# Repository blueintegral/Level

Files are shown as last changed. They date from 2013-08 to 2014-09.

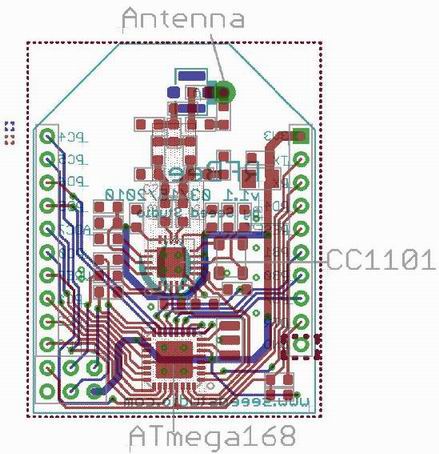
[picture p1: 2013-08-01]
hardware/reference/RFBee-board.jpg

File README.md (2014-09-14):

## Level
#### A node for cognitive radio networks
---
Level is a small, low power and low bandwidth radio for creating and researching cognitive radio networks. It is still in a prototype phase. See the platform paper for a more detailed overview.

###Building
There are two methods to build the firmware. You can use TI's [Code Composer Studio](http://www.ti.com/tool/ccstudio), which is an Eclipse based IDE. Just create a new project and import the files in the firmware/levelfirmware directory. You'll also need to set the target chip to be the cc430f3157.

 You can also use [msp430-gcc](https://github.com/sergiocampama/Launchpad/blob/master/README.md), which has a more libre license than Code Composer Studio. Some of the source files must be modified slightly since interrupt service routine syntax is slightly different. To build, cd into the firmware/levelfirmware/msp430-gcc directory and run "make". To reset the build, run "make clean". 

To save time, I've also been using SimpliciTI as a mesh networking stack. This isn't as free-as-in-speech as I'd like, and I plan on moving away from it. Until then, the license for that code is below.

###License 
The MIT License (MIT)

Copyright (c) [2014] [Hunter Scott]

Permission is hereby granted, free of charge, to any person obtaining a copy
of this software and associated documentation files (the "Software"), to deal
in the Software without restriction, including without limitation the rights
to use, copy, modify, merge, publish, distribute, sublicense, and/or sell
copies of the Software, and to permit persons to whom the Software is
furnished to do so, subject to the following conditions:

The above copyright notice and this permission notice shall be included in all
copies or substantial portions of the Software.

THE SOFTWARE IS PROVIDED "AS IS", WITHOUT WARRANTY OF ANY KIND, EXPRESS OR
IMPLIED, INCLUDING BUT NOT LIMITED TO THE WARRANTIES OF MERCHANTABILITY,
FITNESS FOR A PARTICULAR PURPOSE AND NONINFRINGEMENT. IN NO EVENT SHALL THE
AUTHORS OR COPYRIGHT HOLDERS BE LIABLE FOR ANY CLAIM, DAMAGES OR OTHER
LIABILITY, WHETHER IN AN ACTION OF CONTRACT, TORT OR OTHERWISE, ARISING FROM,
OUT OF OR IN CONNECTION WITH THE SOFTWARE OR THE USE OR OTHER DEALINGS IN THE
SOFTWARE.

All SimpliciTI code is distributed under TI's license agreement, which can be found in "SimpliciTI License Agreement.pdf".

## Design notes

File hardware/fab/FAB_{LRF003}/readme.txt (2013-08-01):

Company Name:         Level RF
PC Board Name:        Level Shield
PC Board Number:      -
Revision:             4
Design House:         Clear River Technical Services Corporation
Designed by:          Tom Atkinson
Contact Number:       (603) 505 - 2376
e-mail:               toma@crtscorp.com

Files Included:

Filename		Description						Format
--------		-----------						------
L1.PHO			Primary Side Cu					Gerber 8.5
L2.PHO			Layer 2   Cu					Gerber 8.5
L3.PHO			Layer 3   Cu					Gerber 8.5
L4.PHO			Secondary Side Cu				Gerber 8.5
PSS.PHO			Primary Silkscreen A/W				Gerber 8.5
SSS.PHO			Secondary Silkscreen A/W			Gerber 8.5
PSM.PHO			Primary Soldermask A/W				Gerber 8.5
SSM.PHO			Secondary Soldermask A/W 			Gerber 8.5
PST.PHO			Primary Solder Stencil A/W 			Gerber 8.5
SST.PHO			Secondary Solder Stencil A/W			Gerber 8.5	  
DD.PHO			Drill Drawing  					Gerber 8.5
DD.PDF			PDF of Drill Drawing				Adobe PDF file
NC_DRILL.DRL		NC Drill Data					NC DRILL ASCII																
NC_DRILL.REP		Drill Tool Listing				ASCII
NC_DRILL.LST		Drill X-Y Listing				ASCII
IPCD356.NET		IPC-D-356 Netlist				IPC-D-356 ASCII
README.TXT		This File					ASCII

NOTES: 

1) USE FILM OUTLINE CORNERS TO ALIGN ARTWORKS

2) ALL THERMALS ARE O.D.  I.D.= O.D. - .020
   WITH A .015 OPEN AT 45 DEGREES.

3) ALL VIAS SHALL HAVE A DIRECT CONNECTION
   TO THE PLANE. NO THERMALS ON VIAS.

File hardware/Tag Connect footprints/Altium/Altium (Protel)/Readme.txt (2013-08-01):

The Protel99 (Now known as ALtium) decals were provided by Martin Hollenweger of 3xS Srl, Italy.

TC2030: Directory containing a protel Project for the TC2030-MCP and the TC2030_MCP-NL
		 TC2030.pfp is the PCB library
		 TC2030.pcb is a example PCB
		 TC2030.ddb is the protel 99SE database file

CAN for TC2030 contains the Gerber and NC-Drill files of the example PCB

WE RECOMMEND CHANGING THE ALIGNMENT PIN HOLES TO BE AT LEAST 0.0374" - see latest drawing at www.Tag-Connect.com

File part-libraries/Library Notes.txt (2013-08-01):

Please add datasheet parameters:
ComponentLink1URL: (datasheet_url)
ComponentLink1Description: Datasheet

Let's keep parts as one block, utilize 'push to sheet' if unwieldy

Set pin inputs / outputs

Create one .schLib per part, helps with version control

Remember to compile, it catches errors

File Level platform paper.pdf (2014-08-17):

# Level: An Open Platform for Sensor Network Development in TV Whitespace

Hunter Scott
School of Electrical and Computer Engineering Georgia Institute of Technology Atlanta, GA
hunter.scott@gatech.edu

Abstract—The rapid proliferation of wireless sensors will require new techniques to handle the corresponding growth in traffic. One of the ways this growth may be addressed is with technology like TV Whitespace. This paper presents a new open source hardware platform to allow students and researchers to cheaply and easily experiment with sensor networks in the TV Whitespace bands as well as other frequency bands. It is hoped that the availability of such a platform will spur innovation in mesh networking, security, dynamic spectrum access, and related areas of research.

Keywords—Whitespace, Cognitive Radio, Security, Sensor Networks

I. INTRODUCTION
TV Whitespace has the potential to be used for a variety of purposes. Most commonly, the viability of delivering internet to rural areas using TV Whitespace as a backhaul is
investigated | [1]. | The | excellent | signal | propagation
characteristics of TV Whitespace also make it ideal for long range wireless sensors. Sensors typically need very little bandwidth and can take advantage of “holes” in the spectrum that would otherwise go unused [2]. Relatively little work has been done in using TV Whitespace in a sensor network. The lack of a suitable hardware platform with which to experiment that is optimized for sensor networks and that can operate in TV Whitespace may be contributing to this phenomenon.

The current generation of hardware solutions for developing and testing sensor networks has several limitations. Most testbeds rely on Zigbee compliant radios like the XBee in conjunction with a microcontroller [3], or a similar integrated mote. The problem with these kinds of devices is that they often do not have significant computing or digital signal processing abilities, and they are restricted in their frequency range to only a few dozen megahertz and are unable to tune to TV band frequencies. Alternatively, some researchers use radios like the Ettus USRP [4, 5] which offers a much larger frequency range that includes the TV band and has the capability of performing intensive computational operations on the data from the radio. The downside of this approach is the cost of the radio, as well as its size and power consumption.

An embedded platform that is capable of transmitting and receiving in TV Whitespace frequencies is needed to allow researchers to begin developing and testing sensor networks in the field. It must be small and power efficient while retaining a large frequency range and must have adequate processing capability. Because no such device existed, the Level platform was developed. A prototype has been built based on the CC430 microcontroller from TI and the ADF4351 wideband synthesizer with integrated VCO from Analog Devices. This paper discusses the design principles of this device in Section 2 as well as the hardware architecture, current capabilities of this device, and possible future improvement in both hardware and software.

II. THE LEVEL PLATFORM

A. Design Principles
A mote for a sensor network that operates in TV Whitespace must be capable of transmitting and receiving from 470 MHz to 700 MHz. It must also be small and power efficient, and must have a suitable processor to handle basic digital signal processing. Because many consumer devices do not have the ability to communicate over TV Whitespace, a way to shift traffic from TV Whitespace to another popular band like Bluetooth or WiFi would also be beneficial. Finally, the mote should be easy to debug, as its firmware will likely change often during the course of research. To achieve these design principals, the device should also incorporate publicly available components rather than custom ASICs so that parts can be replaced easily and modifications to the design are easy to make.
B. Hardware Architecture
The Level platform is based on a 16 bit CC430F5137 microcontroller. This microcontroller utilizes a von Neumann architecture and incorporates an RF transceiver core from the sub-GHz CC1101. The CC430F5137 contains a 12 bit ADC, a critical component for sensors to capture data from their environment at an acceptable resolution, and a hardware implementation of AES-128, meaning the CPU can be saved for other operations while still ensuring that all traffic across the network is encrypted.

The CC1101 RF transceiver core is only capable of operating in the 315/433/868/915 MHz bands. To be capable of operating in TV Whitespace across 470-700 MHz, a transverter was implemented. The ADF4351 wideband synthesizer with integrated VCO is used as a local oscillator and, after being filtered, is mixed through an ADEX-10L passive mixer. The CC430F5137 RF output is sent through a SAW filter before going into the mixer. The output of the mixer is then sent through a series of filters, amplifiers, and RF switches. Since only a single antenna is used, the microcontroller switches the signal path from the antenna to the transmitting or receiving path when appropriate.

C. Current Capabilities
Currently, the Level platform is able to transmit and receive from 35 MHz to 1500 GHz. It consumes a maximum of approximately 356 mA, although it is able to go into several power saving modes that can reduce this by a great deal. The Level platform has two “taps” in the form of directional couplers, one on the output of the CC430F5137 and one on the output of the ADF4351. These can be used to assist in debugging during development by allowing the user to observe the local oscillator or RF transceiver outputs independent of the mixer, filters, and amplifiers.

The mechanical design of the Level platform was designed to fit into the “shields”, or daughterboards, that attach to a popular hobbyist microcontroller called the Arduino. Rather than include a WiFi or Bluetooth IC directly on the Level platform, the ability to use existing daughterboards allows the user to add whichever additional communication device they would like and change them with ease. Examples of daughterboards that are available include Ethernet, WiFi, Bluetooth, GSM, and Zigbee. Because these daughterboards all communicate over SPI on common pins, the Level platform is compatible with all of them and can act as a bridge between TV Whitespace and any of those protocol stacks. The Level platform can also use the same set of pins to potentially interact with another processor if it is necessary to offload some of the processing requirements. A photograph of the Level platform is shown in figure 1.

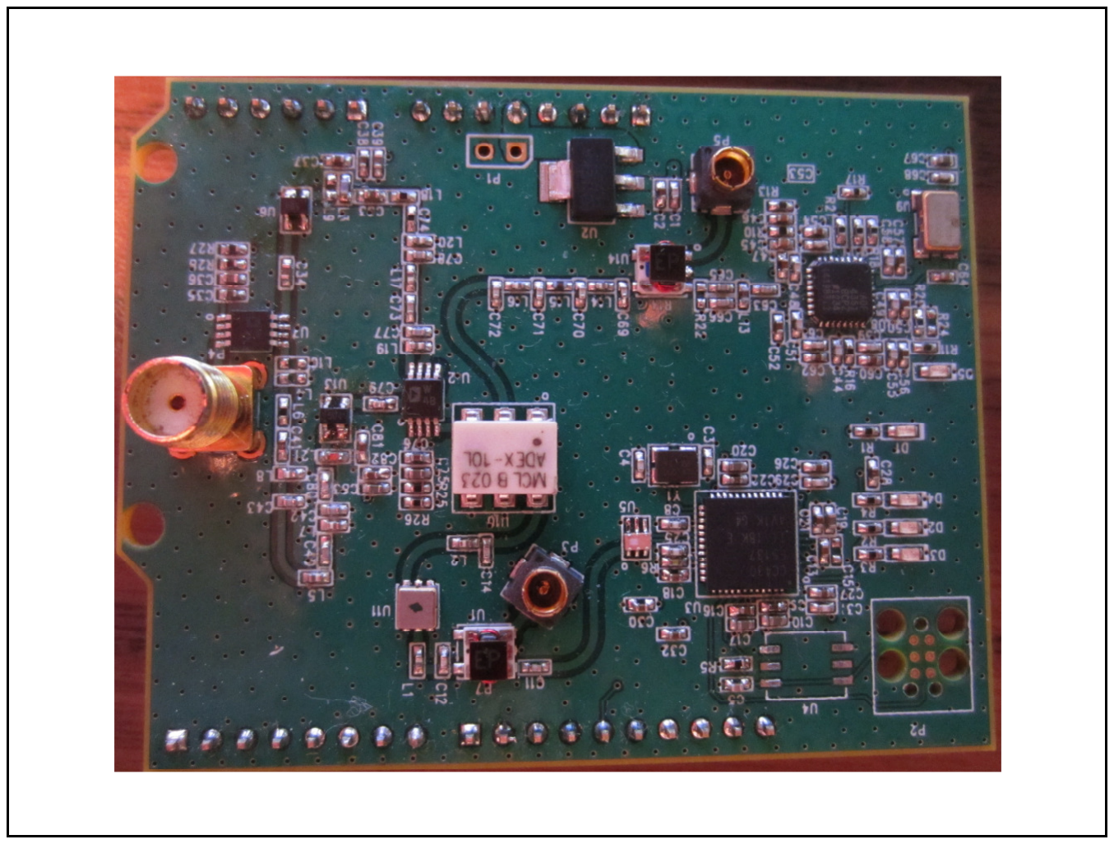
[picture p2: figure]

Fig. 1. The Level hardware platform.

D. Future Work
The Level platform hardware and software is open source, and others are encouraged to improve and expand the capabilities of the device. Several improvements are possible in the current design. For example, the ADF4351 is capable of outputting from 35 MHz to 4.4 GHz, but the mixer can only handle up to 1.5 GHz. By changing the mixer, it should be possible to increase the frequency range of the Level platform. The filters offer another avenue for improvement. All the filters on the device are high order Chebyshev filters. This makes them have a very sharp and precise cutoff, but it also means they have a lower Q than a lower order filter. Further analysis on the tradeoff between good cutoff and high Q could be performed using experimental data from a test deployment to optimize the filters.

The software offers many opportunities for optimization as well. The Level platform is designed to comply with the FCC rules for a mobile device in TV Whitespace wherein the base station commands the mobile device with what frequency and bandwidth to use. However, spectrum sensing using Fourier analysis can be implemented to help inform the base station about the spectral environment [6].

Security in TV Whitespace and other similar cognitive radio protocols is an important research area in determining if and how cognitive radio can be used commercially outside of research [7]. The Level platform can be used to not only test security in sensor networks based on TV Whitespace, but it can also be used to test backhaul links and other applications of TV Whitespace. Additionally, because the Level platform is capable of transmitting on ISM band frequencies, it can be used to test and attack other ISM band devices.

REFERENCES

[1] | Gerami, | Cyrus, | Narayan | Mandayam, | and | Larry | Greenstein.
"Backhauling in TV White Spaces." Global Telecommunications Conference (GLOBECOM 2010), 2010 IEEE. IEEE, 2010.
[2] Čabrić, Danijela, et al. "A cognitive radio approach for usage of virtual unlicensed spectrum." 14th IST Mobile and Wireless Communications Summit. 2005.
[3] Boonsawat, Vongsagon, et al. "XBee wireless sensor networks for temperature monitoring." the Second Conference on Application Research and Development (ECTI-CARD 2010), Chon Buri, Thailand.
| 2010.
[4] Gollakota, Shyamnath, and Dina Katabi. Zigzag decoding: combating hidden terminals in wireless networks. Vol. 38. No. 4. ACM, 2008.
[5] Yan, Zhi, et al. "Spectrum sensing, access and coexistence testbed for cognitive radio using USRP." Circuits and Systems for Communications, 2008. ICCSC 2008. 4th IEEE International Conference on. IEEE, 2008.
[6] Ji, Zhu, and KJ Ray Liu. "Cognitive radios for dynamic spectrum
access-dynamic | spectrum | sharing: | A | game | theoretical
overview." Communications Magazine, IEEE 45.5 (2007): 88-94.
[7] Clancy, T. Charles, and Nathan Goergen. "Security in cognitive radio networks: Threats and mitigation." Cognitive Radio Oriented Wireless Networks and Communications, 2008. CrownCom 2008. 3rd International Conference on. IEEE, 2008.

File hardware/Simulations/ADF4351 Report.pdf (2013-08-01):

Design1 analysed at 09/26/12 22:33:03

PLL Chip is ADF4351
VCO is ADF4351
Reference is custom

Advanced Design - VCO Divider is Outside loop and set as follows:
Start Freq | Stop Freq | VCO Divider Channel Spacing
470MHz | 550MHz | 8 | 25.0kHz
550MHz | 698MHz | 4 | 50.0kHz

Loop Filter designed at a VCO frequency of 3.1113GHz with a Kv of 38.66MHz/V

Frequency Domain Analysis of PLL
Analysis at PLL output frequency of 572.75MHz

Phase Noise Table
Freq | Total | VCO | Ref | Chip | SDM | Filter
100 | -96.65 | -98.77 | -- | -100.8 | -265.7 | -154.3
1.00k | -93.70 | -93.81 | -- | -110.0 | -225.5 | -134.4
10.0k | -94.71 | -94.77 | -- | -114.1 | -183.0 | -120.9
100k | -125.6 | -125.6 | -- | -151.9 | -178.8 | -150.8
1.00M | -145.5 | -145.5 | -- | -209.0 | -195.8 | -189.1

Reference Spurious
Noise and Jitter Calculations include the first 10 ref spurs
First three spurs: -300 dBc -300 dBc -300 dBc

Fractional-N Spur Estimate (worst case)
Phase Detector mode is Dither OFF
Freq (Hz) | Spur Level (dBc)
100k | -90.2
200k | -106
300k | -116

Phase jitter using brick wall filter from 10.0kHz to 100kHz
Phase Jitter 0.12 degrees rms

ACP - Channel 1
Channel 1 is centred 25.0kHz from carrier with bandwidth 15.0kHz Power in channel = -62.4dBc

---- End of Frequency Domain Results ----

Transient Analysis of PLL
Frequency change from 470MHz to 698MHz Simulation run for 1.15ms

Frequency Locking
Time to lock to 1.00kHz is 294us
Time to lock to 10.0 Hz is 441us

Phase Locking (VCO Output Phase) Time to lock to 10.0 deg is 298us
Time to lock to 1.00 deg is 372us

Lock Detect Threshold
Time to lock detect exceeds 2.50 V is 135us

---- End of Time Domain Results ----

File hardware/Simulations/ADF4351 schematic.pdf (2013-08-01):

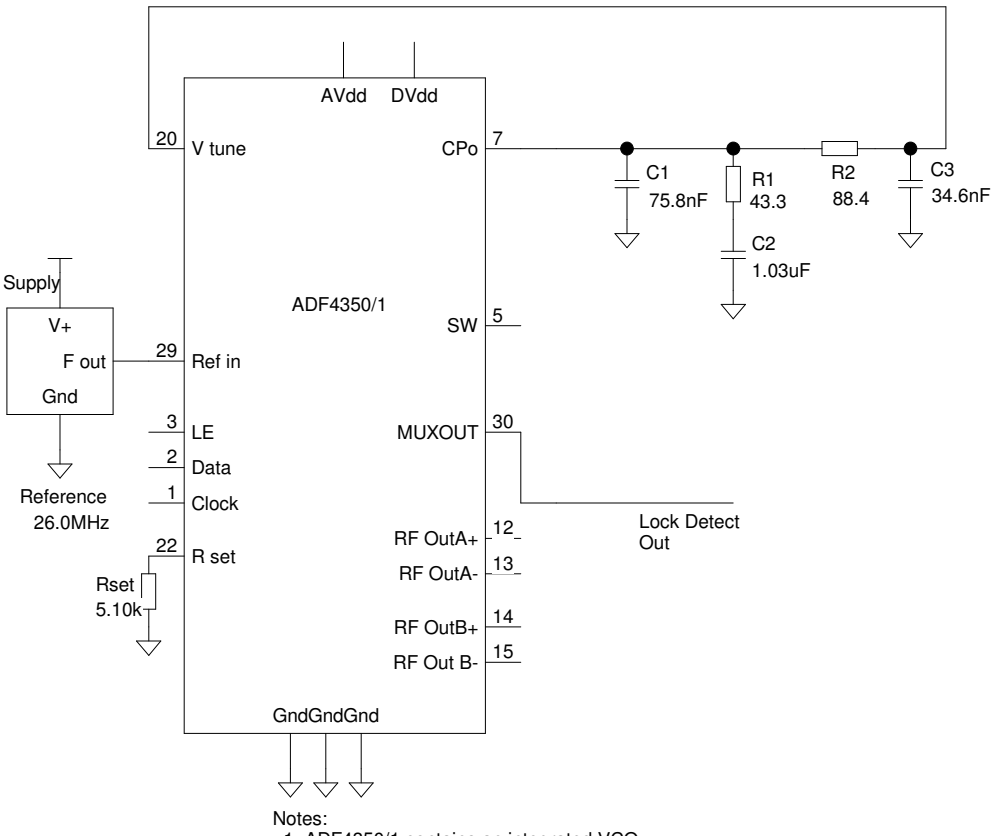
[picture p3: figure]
RF OutA-; RF OutA+; Rset 5.10k; ADF4350/1; AVdd; DVdd; Clock 1; Data 2; GndGndGnd; MUXOUT; R set 22; Notes:; Ref in 29; V tune 20; CPo; RF OutB+; RF Out B-; Lock Detect Out; F out; Gnd; Reference 26.0MHz; V Supply

### 1. ADF4350/1 contains an integrated VCO 2. Consult datasheet for full pinout detail

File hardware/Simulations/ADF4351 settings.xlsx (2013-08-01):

System
Min freq | 470 MHz
Max freq | 698 MHz
Channel Spc | 50.00 kHz
PD freq | 26.0 MHz
Ref Divider | 1
Ref Doubler | disabled
Modulus | 130
Design freq | 777.8175 MHz
Reference | custom
Freq | 26.0 MHz
Phase noise | none
VCO | ADF4351
Tuning Law | Muiltiband
Input cap | 0F
Divider N | 4
Phase noise | Table
PN floor | -153 dBc/Hz
Chip | ADF4351
Mode | Normal
Main divider
Prescaler P | 8
Min cgts div | 75
counter bits | Not used
min value | 75
Max freq | 4.40 GHz
Max PS out freq | 900 MHz
Min freq | 34.4 MHz
Ref Divider
counter bits | 10
Min value | 0.5
Max freq | 250 MHz
Min freq | 0 Hz
Phase Detector | Charge Pump
Rset | 5.10k
Vx | 25.5 V
R0 | 0
Rset Min | 2.70k
Rset Max | 10.0k
Rset Nom | 5.10k
CP current | 5.00mA
Polarity | positive
Leakage | 0A
ABPulse | 6.00 ns
Vp | 5.00 V
Vmin | 0 V
Vmax | 5.00 V
Max freq | 90.0 MHz
Noise mode | Dither OFF
PN floor | -220 dBc/Hz
1/f PN@10kHz | -116 dBc/Hz
CSR | OFF
FracN Spur Base | -45.0 dBc
SDM order | 3
Lock detect | Dig filter
Vhigh | 3.00 V
Vlow | 0 V
T Pass | 6.00 ns
N Pass | 40
T Fail | 25.0 ns
Speedup mode | None
Aux outputs
Rfout_B | Disable
Loop Filter | CPP_3C
Specify | Phase margin
loop bandwidth | 10.0 kHz
Phase margin | 45.0 deg
Zero loc | 3.57 kHz
pole loc | 28.0 kHz
Last pole | 100 kHz
C1 | 75.8 nF
R1 | 43.4
C2 | 1.03 uF
R2 | 88.4
C3 | 34.6 nF
Lock Detect | Dig filter
Freq Domain
min freq | 100 Hz
max freq | 1.00 MHz
Pts per decade | 10
Analysis at | 572.75 MHz
Int (N) | 88
Frac (F) | 15
Time Domain
Type | Freq change
Start Freq | 470 MHz
New Freq | 698 MHz
Stop time | 1.15 ms
Max time step | 1.92 ns
VCO autocal | enable
BSC Div | 52

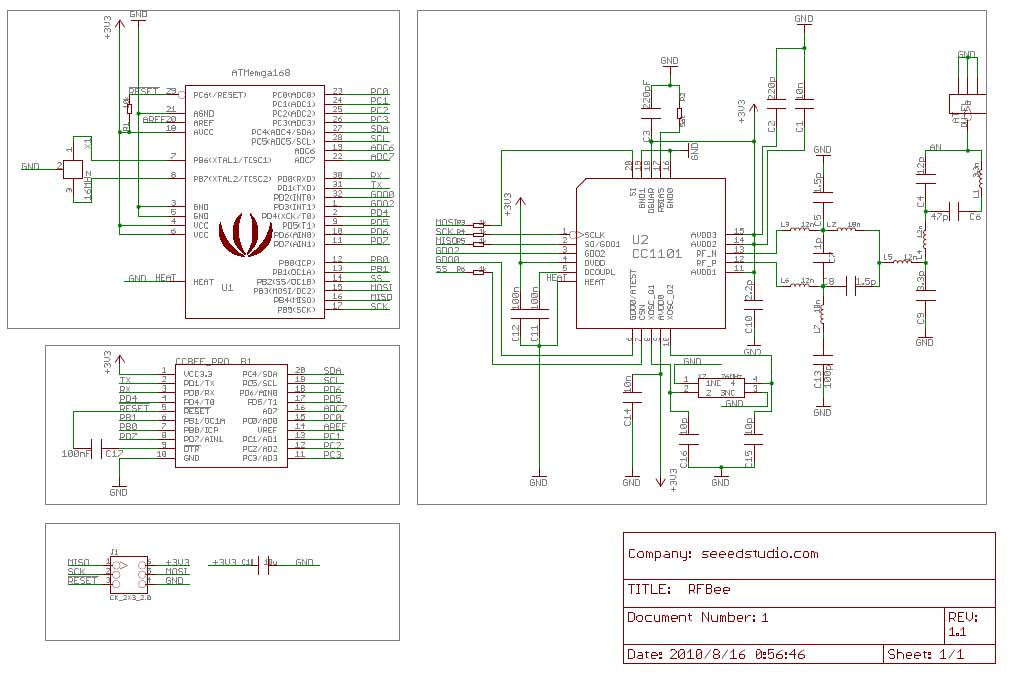
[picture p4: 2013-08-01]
hardware/reference/RFBee-sch.jpg

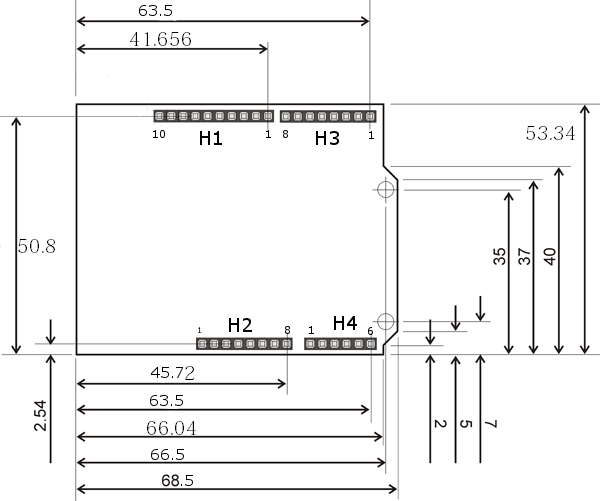
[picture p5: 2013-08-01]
hardware/mech_drawing.png

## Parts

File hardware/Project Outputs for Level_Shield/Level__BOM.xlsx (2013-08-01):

Description | Designator | Footprint | LibRef | Quantity | Value
Capacitor (Semiconductor SIM Model) | C1, C48, C49, C51, C53, C55, C58, C59, C61, C68, C69, C72 | 0402 | Cap Semi | 12 | 10pF
Capacitor (Semiconductor SIM Model) | C2, C26, C27, C28, C30, C32, C47, C50, C52, C54, C56, C57, C60, C62 | 0402 | Cap Semi | 14 | 0.1uF
Capacitor (Semiconductor SIM Model) | C3, C4 | 0402 | Cap Semi | 2 | 27pF
Capacitor (Semiconductor SIM Model) | C5 | 0402 | Cap Semi | 1 | 0.0022uF
Capacitor (Semiconductor SIM Model) | C6, C7, C9, C16, C18, C21, C22, C23, C24, C35, C37, C38, C76, C79, C80, C81, C82 | 0402 | Cap Semi | 17 | 100nF
Capacitor (Semiconductor SIM Model) | C8, C25, C29 | 0402 | Cap Semi | 3 | 2pF
Capacitor (Semiconductor SIM Model) | C10, C17, C19, C20, C33, C34, C36, C39, C67, C75, C83 | 0402 | Cap Semi | 11 | 10uF
Capacitor (Semiconductor SIM Model) | C11 | 0402 | Cap Semi | 1 | 100pF
Capacitor (Semiconductor SIM Model) | C12, C14 | 0402 | Cap Semi | 2 | 2.7pF
Capacitor (Semiconductor SIM Model) | C13 | 0402 | Cap Semi | 1 | 470nF
Capacitor (Semiconductor SIM Model) | C15 | 0402 | Cap Semi | 1 | DNP
Capacitor (Semiconductor SIM Model) | C31 | 0402 | Cap Semi | 1 | 2.0pF
Capacitor (Semiconductor SIM Model) | C40, C73 | 0402 | Cap Semi | 2 | 0.8pF
Capacitor (Semiconductor SIM Model) | C41, C74 | 0402 | Cap Semi | 2 | 0pF
Capacitor (Semiconductor SIM Model) | C42, C43, C77, C78 | 0402 | Cap Semi | 4 | 13.8pF
Capacitor (Semiconductor SIM Model) | C44 | 0402 | Cap Semi | 1 | 532pF
Capacitor (Semiconductor SIM Model) | C45 | 0402 | Cap Semi | 1 | 1.17nF
Capacitor (Semiconductor SIM Model) | C46 | 0402 | Cap Semi | 1 | 15.9nF
Capacitor (Semiconductor SIM Model) | C63, C66 | 0402 | Cap Semi | 2 | 5pF
Capacitor (Semiconductor SIM Model) | C64 | 0402 | Cap Semi | 1 | 1nF
Capacitor (Semiconductor SIM Model) | C65 | 0402 | Cap Semi | 1 | 120pF
Capacitor (Semiconductor SIM Model) | C70, C71 | 0402 | Cap Semi | 2 | 15pF
Typical RED, GREEN, YELLOW, AMBER GaAs LED | D1, D2, D3, D4 | 0603 | LED2 | 4
Typical RED, GREEN, YELLOW, AMBER GaAs LED | D5 | 0603 | LED2 | 1
 | H1 | Header 10x1 8.5mm | IOH | 1
 | H2 | Header 8x1 8.5mm | POWER | 1
 | H3 | Header 8x1 8.5mm | IOL | 1
 | H4 | Header 6x1 8.5mm | AD | 1
Inductor | L1, L2, L14, L16 | 0402 | Inductor | 4 | 18nH
Inductor | L3, L21 | 0402 | Inductor | 2 | 120 ohms @ 100 MHz
Inductor | L4, L9, L10 | 0402 | Inductor | 3 | DNP
Inductor | L5, L17 | 0402 | Inductor | 2 | 0.07uH
Inductor | L6, L18 | 0402 | Inductor | 2 | 0nH
Inductor | L7, L8, L19, L20 | 0402 | Inductor | 4 | 0.004uH
Inductor | L11 | 0402 | Inductor | 1 | 94nH
Inductor | L12, L13 | 0402 | Inductor | 2 | 23nH
Inductor | L15 | 0402 | Inductor | 1 | 19nH
Header, 2-Pin | P1 | HDR1X2 | Header 2 | 1
 | P2 |  | tag-connect | 1
 | P3, P5 |  | MMCX | 2
SMB Straight Connector | P4 | SMB_V-RJ45 | SMB | 1
Semiconductor Resistor | R1, R2, R3, R4 | 0402 | Res Semi | 4 | 330
Semiconductor Resistor | R5 | 0402 | Res Semi | 1 | 47k
Semiconductor Resistor | R6 | 0402 | Res Semi | 1 | 56k, 1%
Semiconductor Resistor | R7, R14, R29 | 0402 | Res Semi | 3 | 0
Semiconductor Resistor | R10 | 0402 | Res Semi | 1 | 23.0k
Semiconductor Resistor | R11 | 0402 | Res Semi | 1 | 1k
Semiconductor Resistor | R13 | 0402 | Res Semi | 1 | 11.3k
Semiconductor Resistor | R16 | 0402 | Res Semi | 1 | 5.1k
Semiconductor Resistor | R17, R18, R19, R21 | 0402 | Res Semi | 4 | 10k
Semiconductor Resistor | R22, R24 | 0402 | Res Semi | 2 | DNP
Semiconductor Resistor | R25, R28 | 0402 | Res Semi | 2 | 68k
Semiconductor Resistor | R26, R27 | 0402 | Res Semi | 2 | 15k
 | U1, U14 |  | DBTC-7-152X+ | 2
 | U2 |  | AP1117 | 1
 | U3 |  | CC430F5137 | 1
 | U4 |  | reset button | 1
Balun | U5 |  | 0896BM15A0001 | 1
LNA | U6, U13 |  | PSA4-5043+ | 2
RF Switch | U7, U12 | ADG918 | ADG918 | 2
VCO | U8 | QFN50P500X500-32VBN | ADF4350 | 1
 | U9 | FOX924 | FOX924 | 1
Passive Mixer | U10 |  | ADEX-10L | 1
 | U11 |  | B3744 | 1
 | Y1 |  | NX3225GA-26MHZ-TI | 1

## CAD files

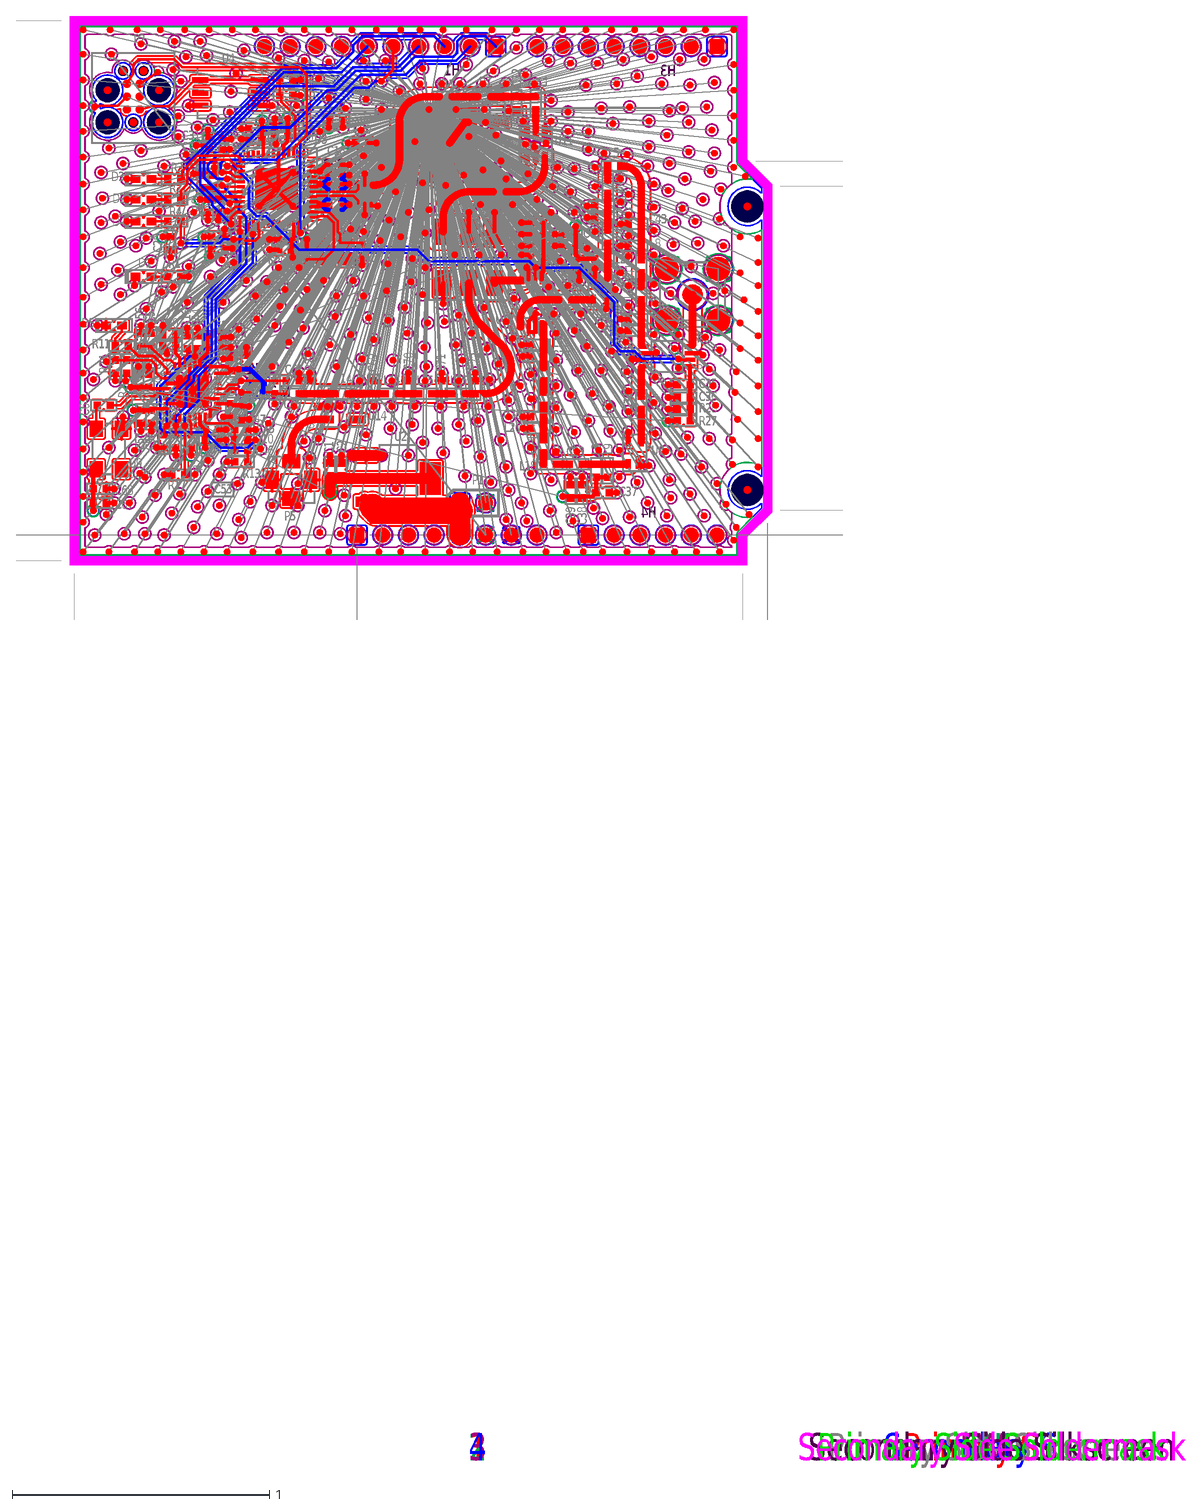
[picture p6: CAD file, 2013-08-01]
hardware/fab/DAT_{LRF003}/{LRF003}LevelShield_4.DXF
1
2
3
4
Primary Side
GND
PWR
Secondary Side
Primary Side Silkscreen
Secondary Side Silkscreen
Primary Side Soldermask
Secondary Side Soldermask
H1
H2
H3
H4
C1
C10
C11
C12
C13
C14
C15
C16
C17
C18
C19
C2
C20
C21
C22
C23
C24
C25
C26
C27
C28
C29
C3
C30
C31
C32
C33
C34
C35
C36
C37
C38
C39
C4
C40
C41
C42
C43
C44
C45
C46
C47
C48
C49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

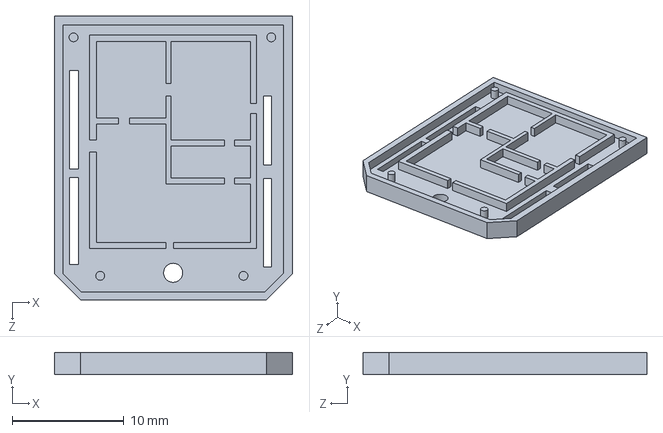
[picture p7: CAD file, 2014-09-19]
mechanical/enclosure top.SLDPRT
21.3 x 2.02 x 25.4 mm

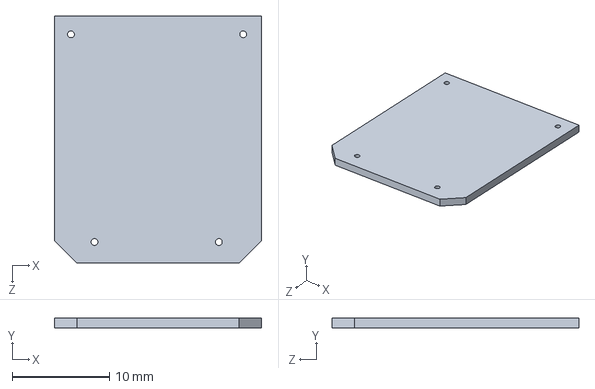
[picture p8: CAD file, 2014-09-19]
mechanical/enclosure bottom.SLDPRT
21.3 x 1.00 x 25.4 mm

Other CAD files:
hardware/Project Outputs for Level_Shield/Level_boardv4.PRT

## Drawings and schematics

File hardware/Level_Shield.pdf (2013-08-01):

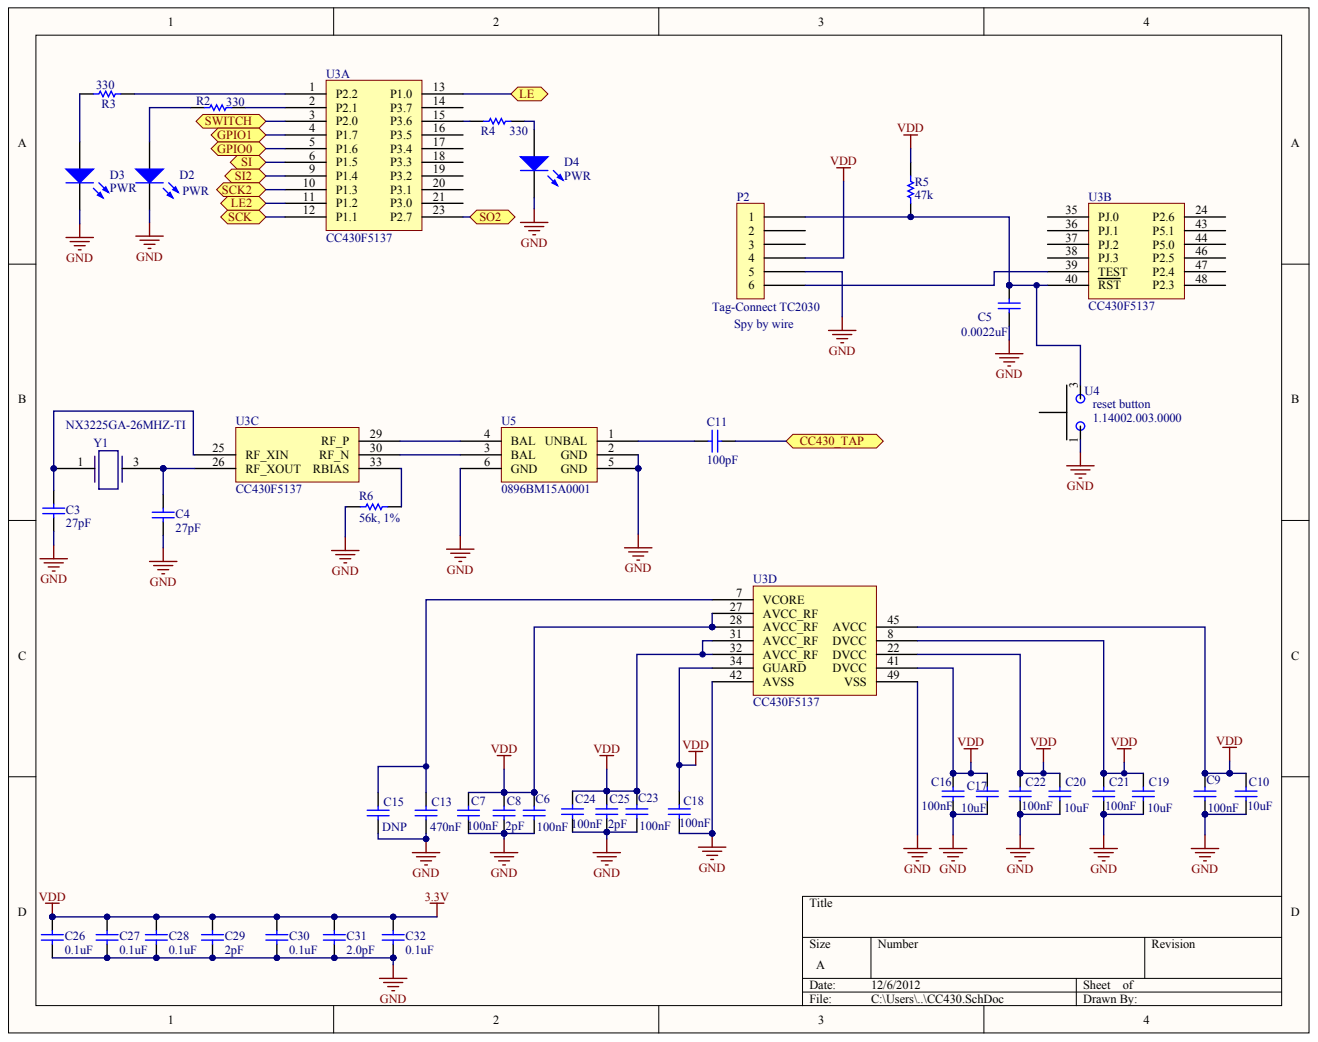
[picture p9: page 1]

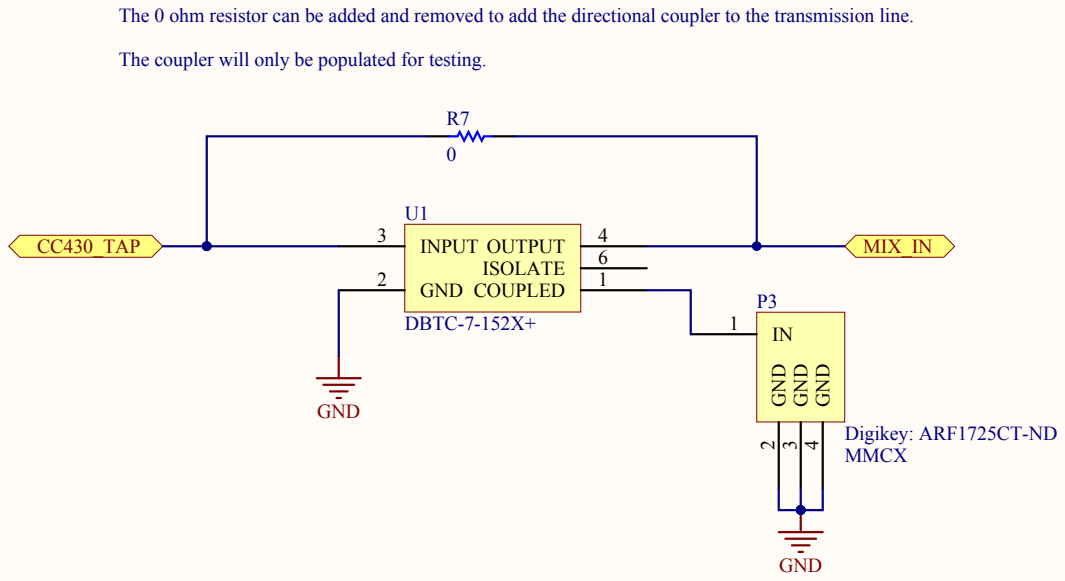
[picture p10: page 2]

The 0 ohm resistor can be added and removed to add the directional coupler to the transmission line.

The coupler will only be populated for testing.

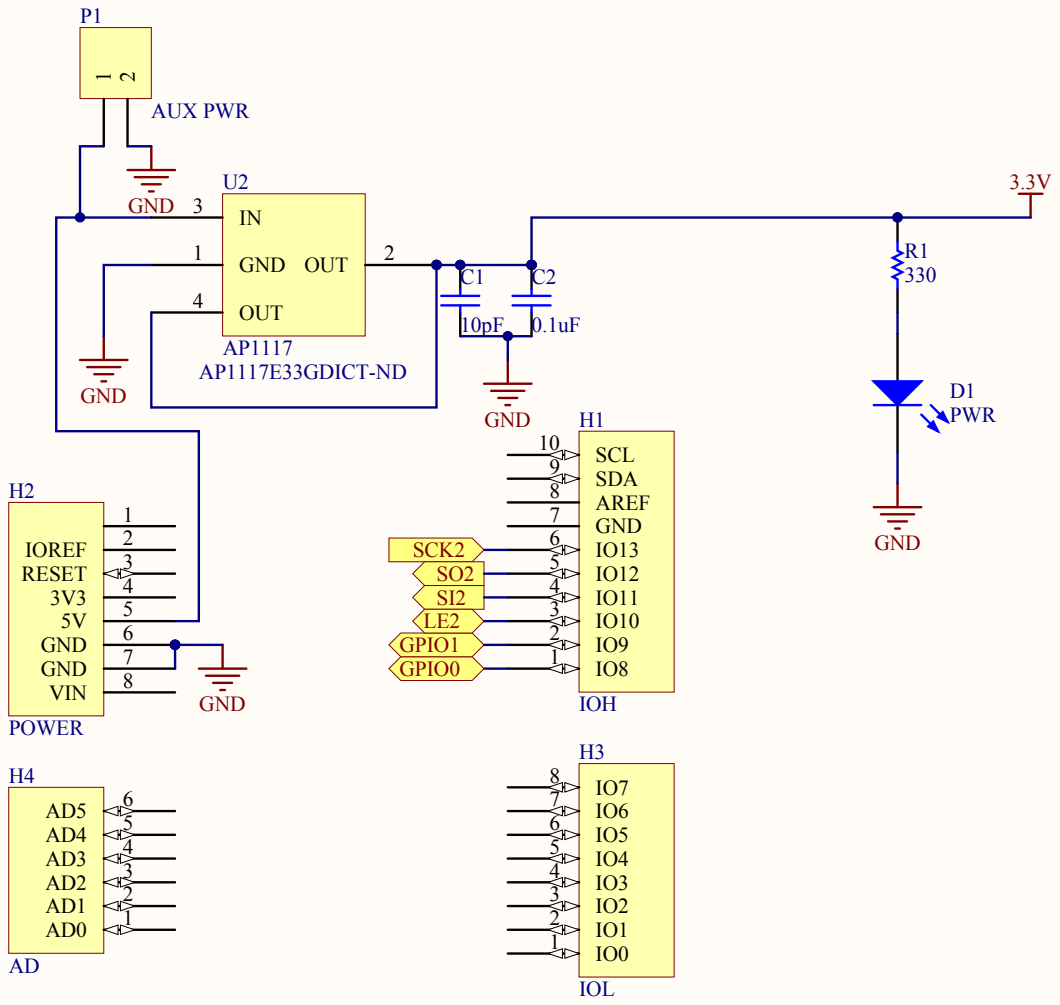
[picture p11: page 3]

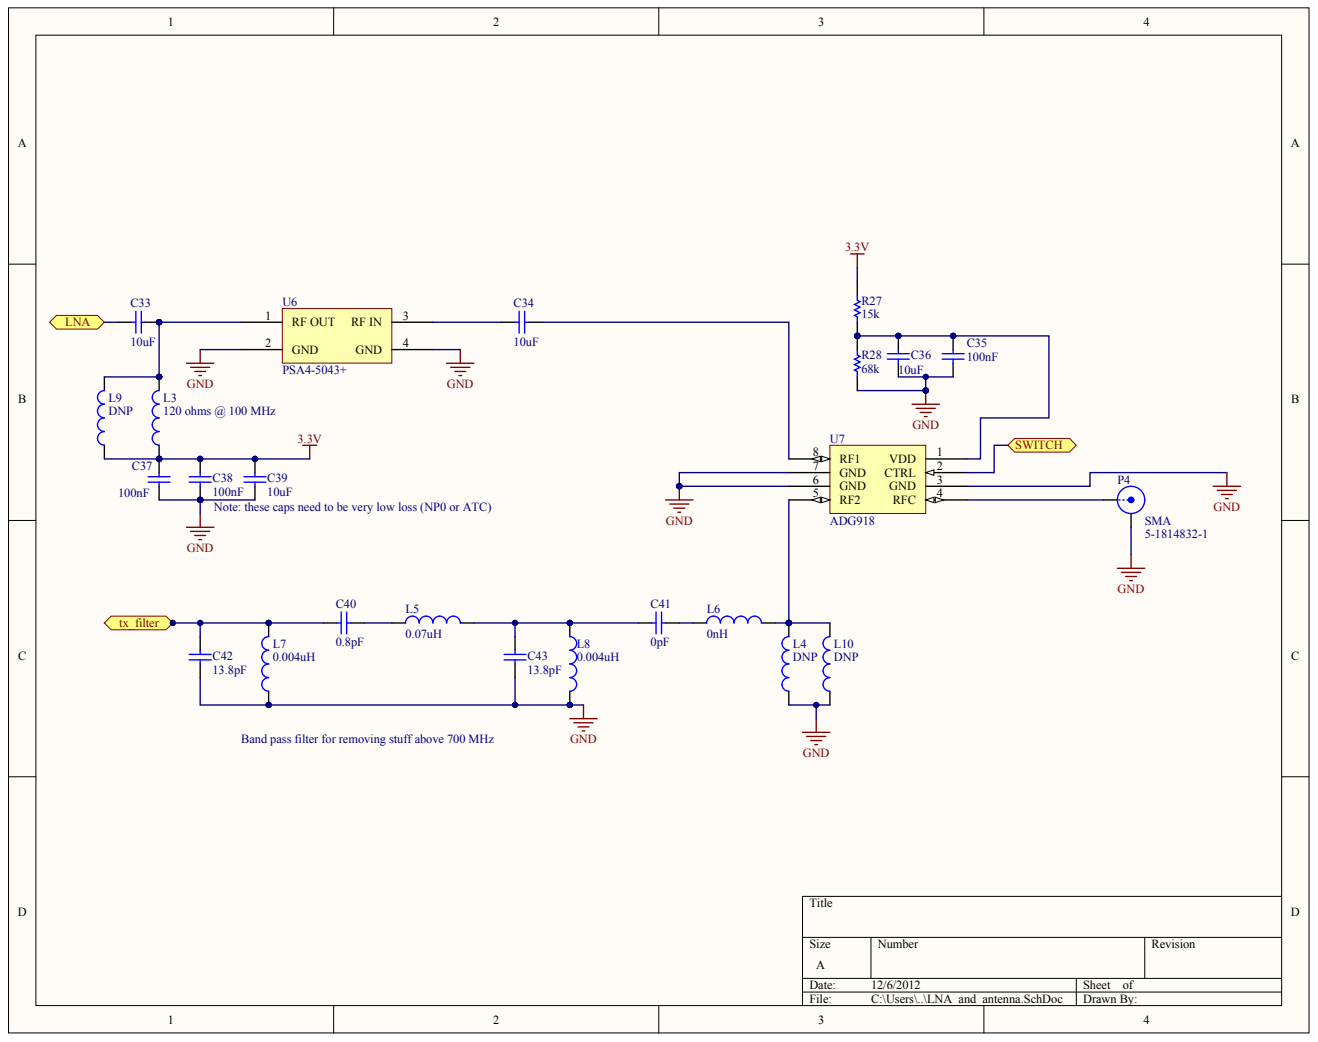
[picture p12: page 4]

Note: these caps need to be very low loss (NP0 or ATC)

Band pass filter for removing stuff above 700 MHz

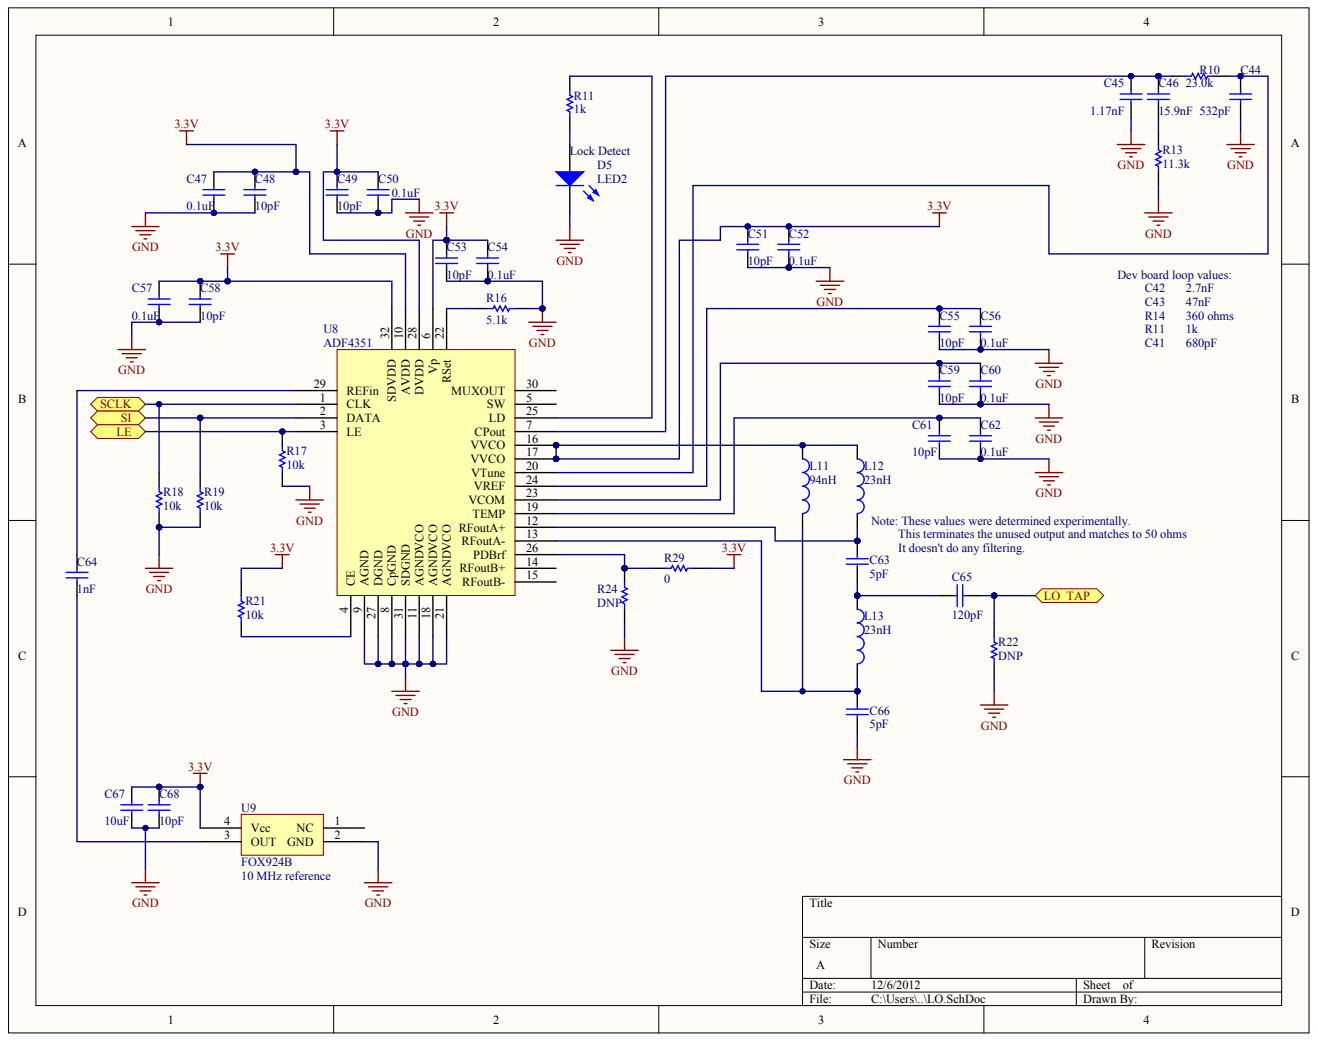
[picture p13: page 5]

Note: These values were determined experimentally.
This terminates the unused output and matches to 50 ohms
It doesn't do any filtering.

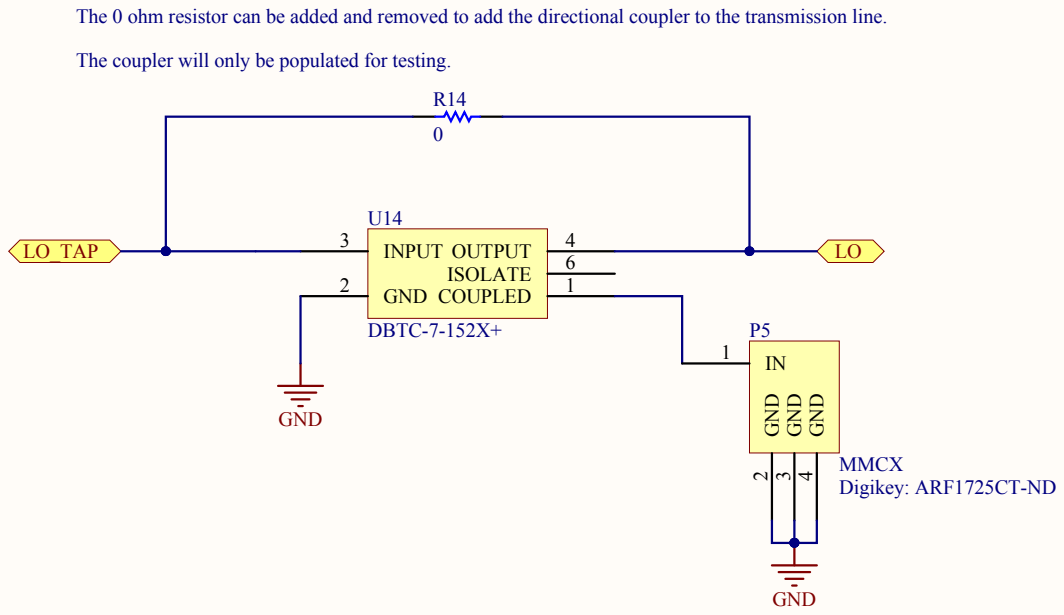
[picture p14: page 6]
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

The coupler will only be populated for testing.

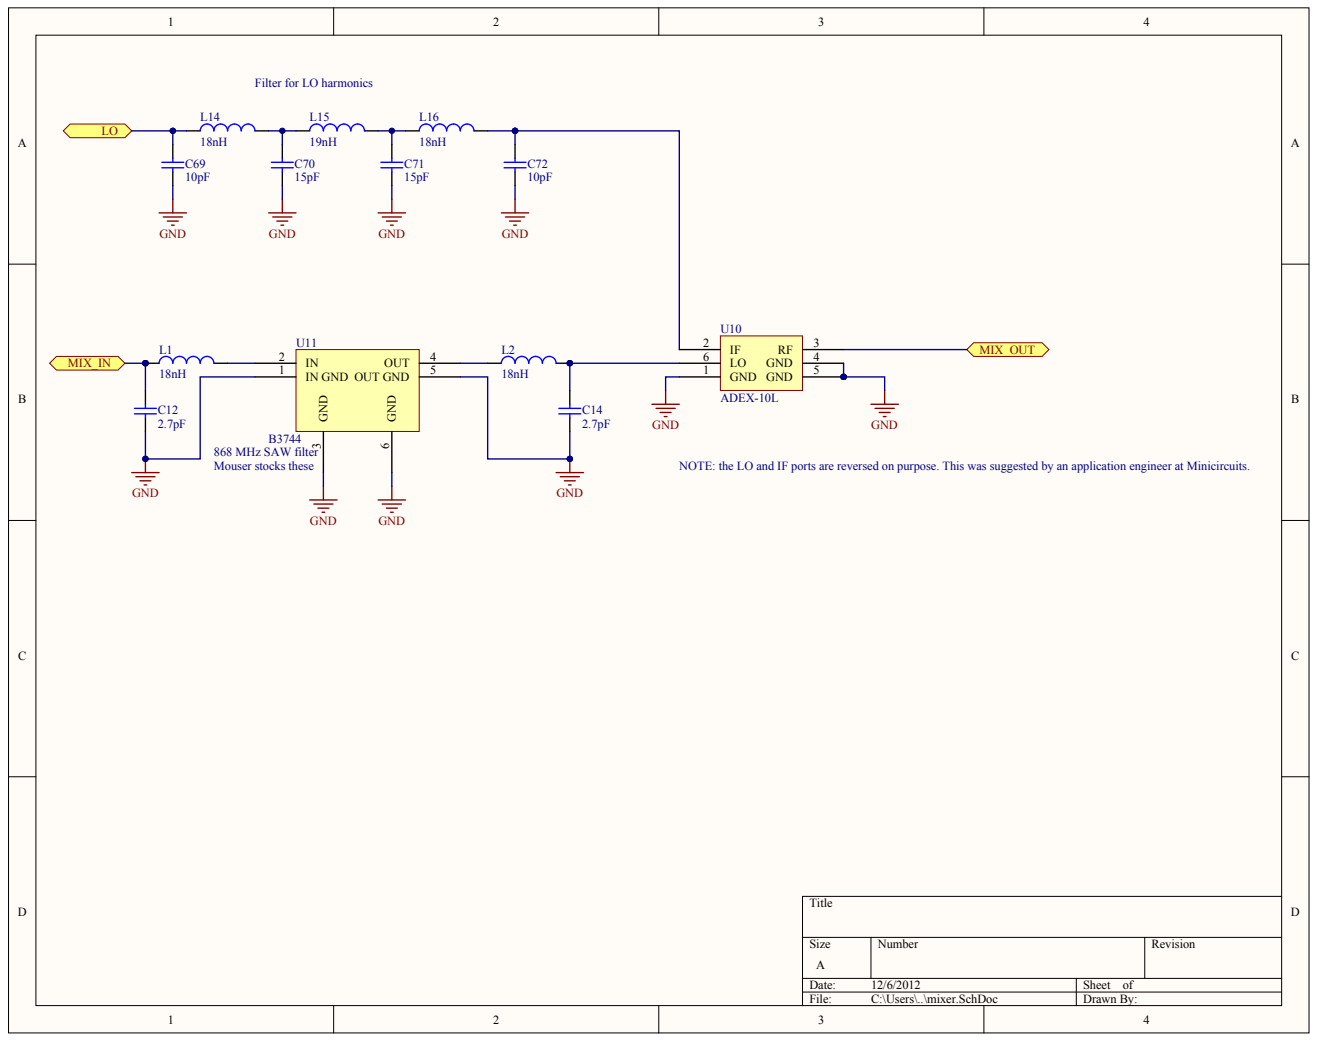
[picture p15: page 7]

Filter for LO harmonics

NOTE: the LO and IF ports are reversed on purpose. This was suggested by an application engineer at Minicircuits.

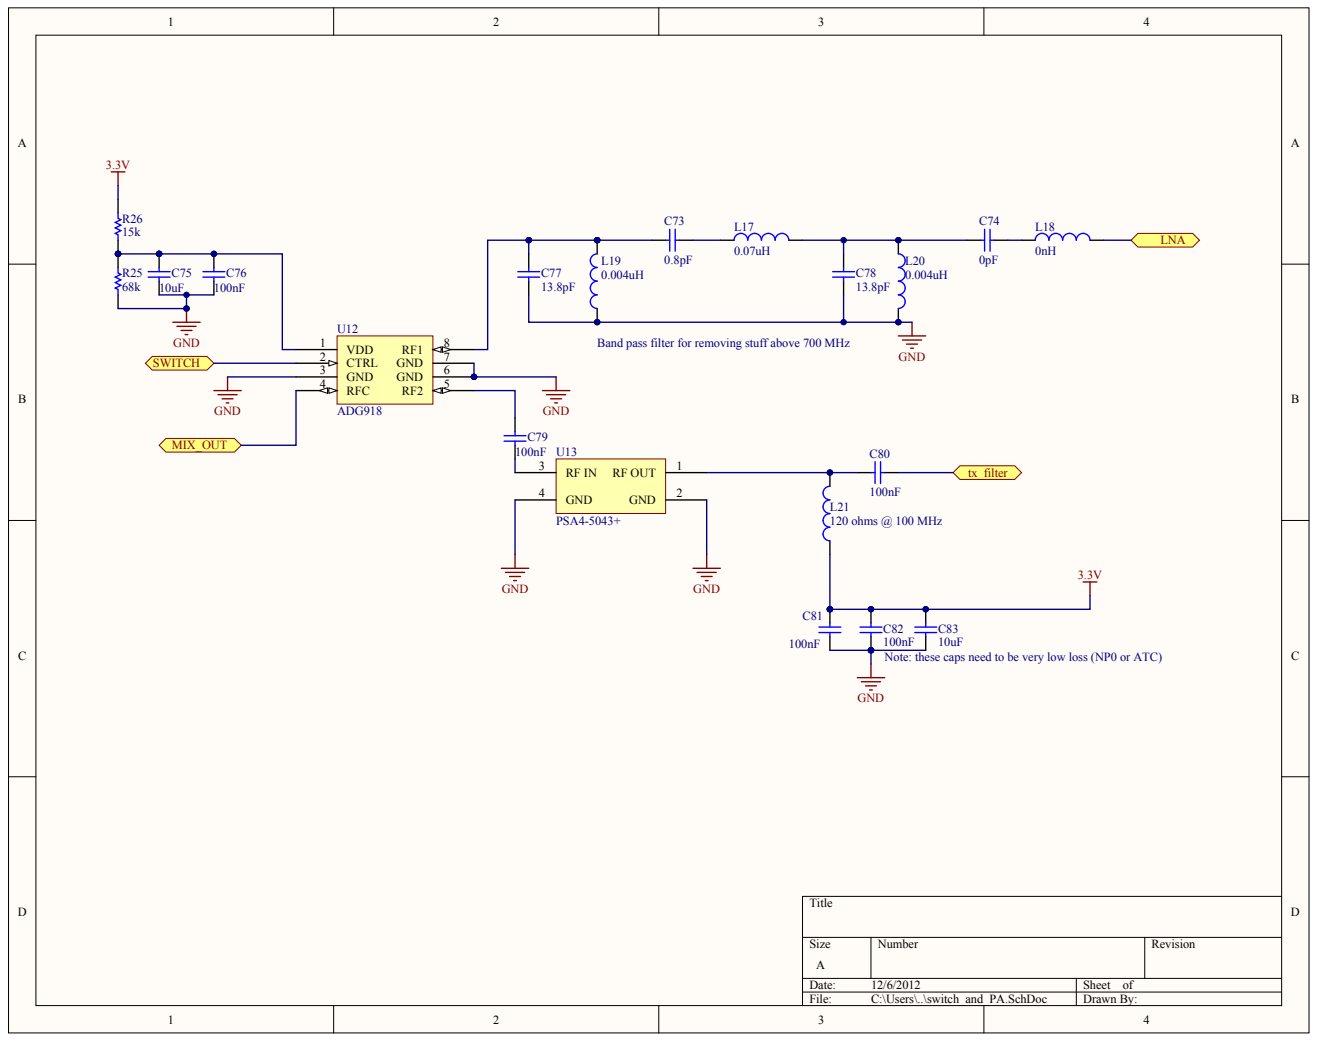
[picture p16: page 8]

Note: these caps need to be very low loss (NP0 or ATC)

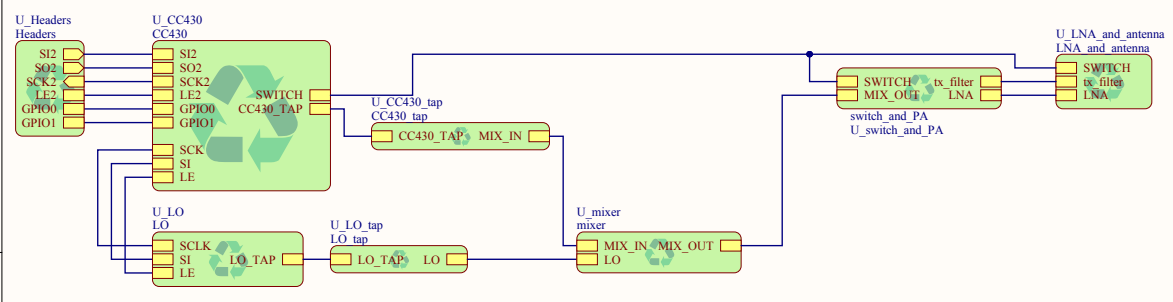
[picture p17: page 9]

Description | Designator | Footprint | LibRef | Quantity | Value
Capacitor (Semiconductor SIM Model) | C1, C48, C49, C51, C53, C55, C58, C59, C61, C68, C69, C72 | 0402 | Cap Semi | 12 | 10pF
Capacitor (Semiconductor SIM Model) | C2, C26, C27, C28, C30, C32, C47, C50, C52, C54, C56, C57, C60, C62 | 0402 | Cap Semi | 14 | 0.1uF
Capacitor (Semiconductor SIM Model) Capacitor | C3, C4 | 0402 | Cap Semi | 2 | 27pF
(Semiconductor SIM Model) | C5 | 0402 | Cap Semi | 1 | 0.0022uF
Capacitor (Semiconductor SIM Model) | C6, C7, C9, C16, C18, C21, C22, C23, C24, C35, C37, C38, C76, C79, C80, C81, C82 | 0402 | Cap Semi | 17 | 100nF
Capacitor (Semiconductor SIM Model) | C8, C25, C29 | 0402 | Cap Semi | 3 | 2pF
Capacitor (Semiconductor SIM Model) | C10, C17, C19, C20, C33, C34, C36, C39, C67, C75, C83 | 0402 | Cap Semi | 11 | 10uF
Capacitor (Semiconductor SIM Model) Capacitor | C11 | 0402 | Cap Semi | 1 | 100pF
(Semiconductor SIM Model) | C12, C14 | 0402 | Cap Semi | 2 | 2.7pF
Capacitor (Semiconductor SIM Model) | C13 | 0402 | Cap Semi | 1 | 470nF
Capacitor (Semiconductor SIM Model) | C15 | 0402 | Cap Semi | 1 | DNP
Capacitor (Semiconductor SIM Model) | C31 | 0402 | Cap Semi | 1 | 2.0pF
Capacitor (Semiconductor SIM Model) Capacitor | C40, C73 | 0402 | Cap Semi | 2 | 0.8pF
(Semiconductor SIM Model) | C41, C74 | 0402 | Cap Semi | 2 | 0pF
Capacitor (Semiconductor SIM Model) | C42, C43, C77, C78 | 0402 | Cap Semi | 4 | 13.8pF
Capacitor (Semiconductor SIM Model) | C44 | 0402 | Cap Semi | 1 | 532pF
Capacitor (Semiconductor SIM Model) | C45 | 0402 | Cap Semi | 1 | 1.17nF
Capacitor (Semiconductor SIM Model) Capacitor | C46 | 0402 | Cap Semi | 1 | 15.9nF
(Semiconductor SIM Model) | C63, C66 | 0402 | Cap Semi | 2 | 5pF
Capacitor (Semiconductor SIM Model) Capacitor | C64 | 0402 | Cap Semi | 1 | 1nF
(Semiconductor SIM Model) | C65 | 0402 | Cap Semi | 1 | 120pF
Capacitor (Semiconductor SIM Model) | C70, C71 | 0402 | Cap Semi | 2 | 15pF
Typical RED, GREEN, YELLOW, AMBER GaAs LED | D1, D2, D3, D4 | 0603 | LED2 | 4
Typical RED, GREEN, YELLOW, AMBER GaAs LED | D5 | 0603 | LED2 | 1
| H1 | Header 10x1 8.5mm | IOH | 1
| H2 | Header 8x1 8.5mm | POWER | 1
| H3 | Header 8x1 8.5mm | IOL | 1
| H4 | Header 6x1 8.5mm | AD | 1
Inductor | L1, L2, L14, L16 | 0402 | Inductor | 4 | 18nH
Inductor | L3, L21 | 0402 | Inductor | 2 | 120 ohms @ 100 MHz
Inductor | L4, L9, L10 | 0402 | Inductor | 3 | DNP
Inductor | L5, L17 | 0402 | Inductor | 2 | 0.07uH
Inductor | L6, L18 | 0402 | Inductor | 2 | 0nH
Inductor | L7, L8, L19, L20 | 0402 | Inductor | 4 | 0.004uH
Inductor | L11 | 0402 | Inductor | 1 | 94nH
Inductor | L12, L13 | 0402 | Inductor | 2 | 23nH
Inductor | L15 | 0402 | Inductor | 1 | 19nH
Header, 2-Pin | P1 | HDR1X2 | Header 2 | 1
| P2 | | tag-connect | 1
| P3, P5 | | MMCX | 2
SMB Straight Connector | P4 | SMB_V-RJ45 | SMB | 1
Semiconductor Resistor | R1, R2, R3, R4 | 0402 | Res Semi | 4 | 330
Semiconductor Resistor | R5 | 0402 | Res Semi | 1 | 47k
Semiconductor Resistor | R6 | 0402 | Res Semi | 1 | 56k, 1%
Semiconductor Resistor | R7, R14, R29 | 0402 | Res Semi | 3 | 0
Semiconductor Resistor | R10 | 0402 | Res Semi | 1 | 23.0k
Semiconductor Resistor | R11 | 0402 | Res Semi | 1 | 1k
Semiconductor Resistor | R13 | 0402 | Res Semi | 1 | 11.3k
Semiconductor Resistor | R16 | 0402 | Res Semi | 1 | 5.1k
Semiconductor Resistor | R17, R18, R19, R21 | 0402 | Res Semi | 4 | 10k
Semiconductor Resistor | R22, R24 | 0402 | Res Semi | 2 | DNP
Semiconductor Resistor | R25, R28 | 0402 | Res Semi | 2 | 68k
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

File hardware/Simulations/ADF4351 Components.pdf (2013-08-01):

# Freq vs Volts

# VCO (div by 4) Phase Noise at 573MHz

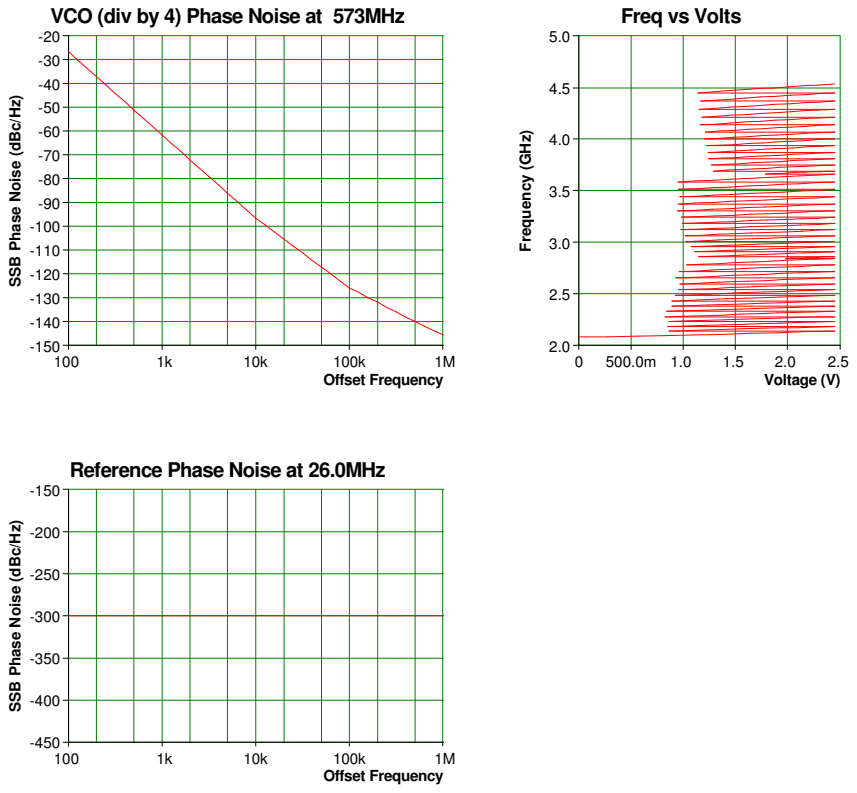
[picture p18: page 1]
Offset Frequency; Voltage (V); Frequency (GHz)

SSB Phase Noise (dBc/Hz)

Reference Phase Noise at 26.0MHz

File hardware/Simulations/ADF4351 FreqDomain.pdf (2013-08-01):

### RFout_A - Phase Noise at 573MHz

### Closed Loop Gain at 573MHz

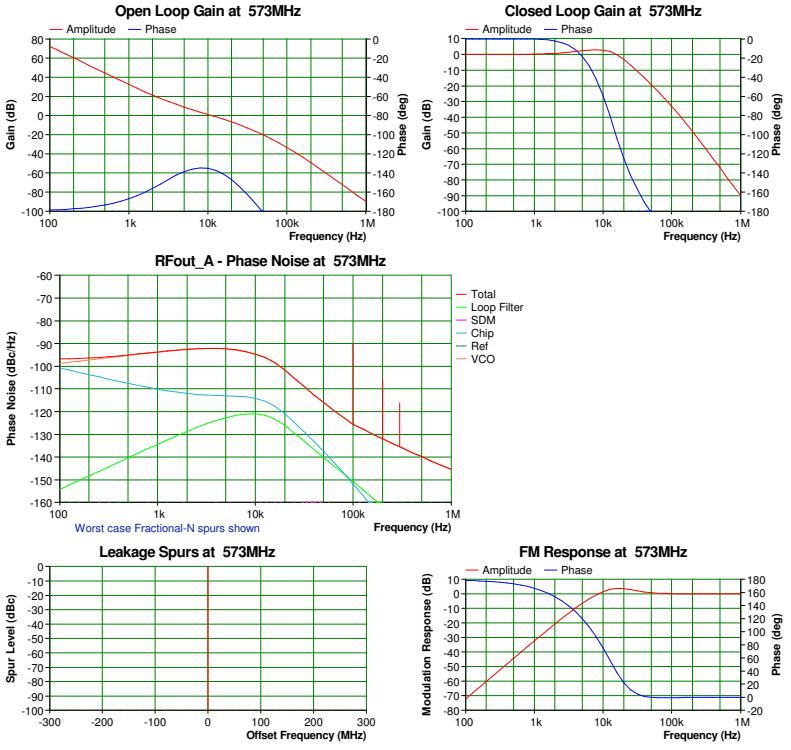
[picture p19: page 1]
Frequency (Hz); Modulation Response (dB); Phase (deg); Amplitude; Phase; Total Loop Filter SDM Chip Ref VCO; Gain (dB)

Open Loop Gain at 573MHz

Phase Noise (dBc/Hz)

Worst case Fractional-N spurs shown
Leakage Spurs at 573MHz

FM Response at 573MHz

Spur Level (dBc)

Offset Frequency (MHz)

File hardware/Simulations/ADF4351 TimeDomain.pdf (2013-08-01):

# Lock Detect Output

## Time (ms)

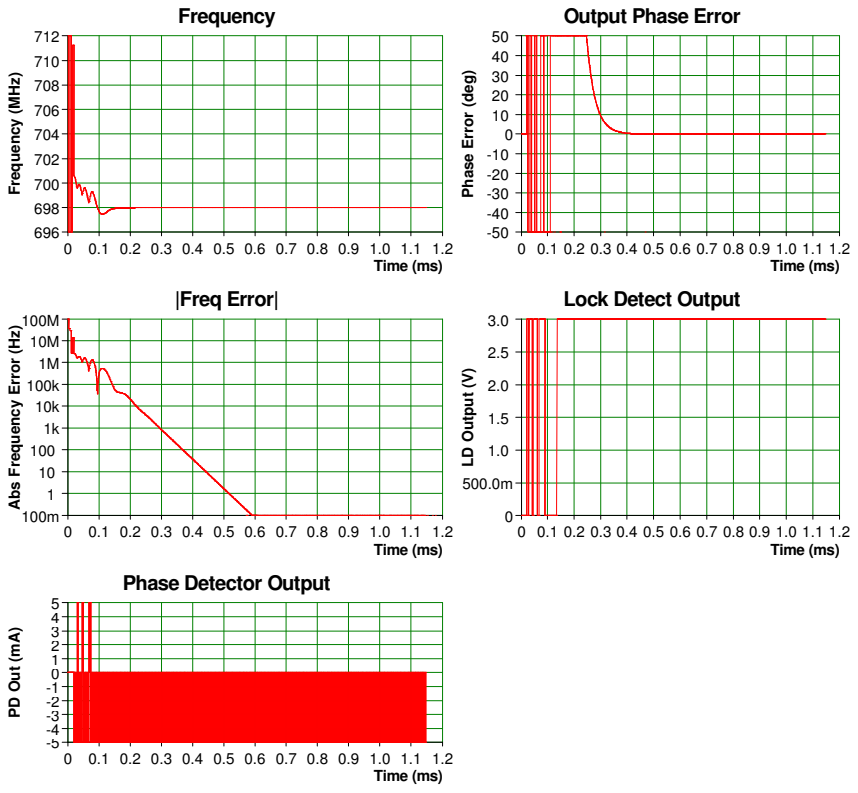
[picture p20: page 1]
0 0.1 0.2 0.3 0.4 0.5 0.6 0.7 0.8 0.9 1.0 1.1 1.2 Time (ms); LD Output (V); Time (ms); |Freq Error|; Frequency (MHz); Frequency

Output Phase Error

Phase Error (deg)

100M Abs Frequency Error ⁽Hz⁾

Phase Detector Output

PD Out (mA)




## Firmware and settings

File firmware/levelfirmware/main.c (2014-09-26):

//Level firmware
//Author: Hunter Scott
//License: MIT

#include <msp430.h> 
#include "cc430x513x.h"
#include "IO.H"
#include "ADF4351.H"
#include "radio.h"
//#include "fix_fft.h"
#include <stdio.h>
#include <stdlib.h>
#include <math.h>

//*****************************************************
//Function definitions
//*****************************************************
void InitSys()
{
	//Set everything up

	//radio stuff
	//P4DIR |= BIT0; // P4.0 output
	//P4OUT = BIT0; // P4.0 High

	// initialize clock module
	P1DIR |= 0x01; // P1.0 output
	UCSCTL3 |= SELREF__REFOCLK;
	UCSCTL4 |= SELA__REFOCLK;

	// initialize Timer_A module
	TA1CCTL0 = CCIE; // CCR0 interrupt enabled
	TA1CCR0 = 32768;
	TA1CTL = TASSEL__ACLK + MC__UP + TACLR; // ACLK, up mode, clear TAR

	#ifdef UART_PRINTF
	// initialize USCI module
	P1SEL |= BIT5 + BIT6 + BIT7; // P1.5,6 = USCI_A0 TXD/RXD
	UCA0CTL1 |= UCSWRST; // **Put state machine in reset**
	UCA0CTL1 |= UCSSEL__ACLK; // AMCLK
	UCA0BR0 = 27; // 32,768kHz 1200 (see User's Guide)
	UCA0BR1 = 0; // 32,768kHz 1200
	UCA0MCTL = UCBRS_2; // 32,768kHz 1200
    UCA0CTL1 &= ~UCSWRST; // **Initialize USCI state machine**
    #endif

}



int main(void) {

	unsigned char TxBuffer[PACKET_LEN]= {
	    0x00, 0x01, 0x02, 0x03, 0x04, 0x05, 0x06, 0x07, 0x08, 0x09,
	    0x10, 0x11, 0x12, 0x13, 0x14, 0x15, 0x16, 0x17, 0x18, 0x19,
	    0x20, 0x21, 0x22, 0x23, 0x24, 0x25, 0x26, 0x27, 0x28, 0x29,
	    0x30, 0x31, 0x32, 0x33, 0x34, 0x35, 0x36, 0x37, 0x38, 0x39,
	    0x40, 0x41, 0x42, 0x43, 0x44, 0x45, 0x46, 0x47, 0x48, 0x49,
	    0x50, 0x51, 0x52, 0x53, 0x54, 0x55, 0x56, 0x57, 0x58, 0x59,
	    0x60, 0x61, 0x62, 0x63, 0x64, 0x65, 0x66, 0x67, 0x68, 0x69,
	    0x70, 0x71, 0x72, 0x73, 0x74, 0x75, 0x76, 0x77, 0x78, 0x79,
	    0x80, 0x81, 0x82, 0x83, 0x84, 0x85, 0x86, 0x87, 0x88, 0x89,
	    0x90, 0x91, 0x92, 0x93, 0x94, 0x95, 0x96, 0x97, 0x98, 0x99,
	};

	unsigned char RxBuffer[PACKET_LEN+2] = {0};


	//Set things up
    WDTCTL = WDTPW | WDTHOLD;	// Stop watchdog timer
	MCU_IO_set();
    InitSys();
    delay (20);
    // PLL_set_frq(); //Program VCO

    //Get radio ready for use
    SetVCore(2);  // Increase PMMCOREV level to 2 for proper radio operation
    ResetRadioCore();
    InitRadio();
    InitButtonLeds();
    // ReceiveOn();

    /*
     * This section sets up the CC430 as an SPI slave and echos out whatever it recieves from the SPI master device.
     * It uses USCI for this. USCI RX ISR is used to handle communication, CPU normally in LMP4. Before the first data
     * exchange, the master pulses the slave RST for complete reset.
     * ACLK = ~32.768kHz, MCLK = SMCLK = DCO ~ 1048kHz
     *
     * If the slave (aka level) is in debug mode, the reset signal from the master will conflict with the slave's
     * JTAG. To work around, use IAR's "Release JTAG on Go" or CCS's "Run Free" on the slave device. If breakpoints are set in the slave RX
     * ISR, the master must be stopped to avoice overrunning the slave RXBUF.
     *
     */

    //                   CC430F5137
    //                 -----------------
    //            /|\ |                 |
    //             |  |                 |
    //    Master---+->|RST          P2.2|-> LED
    //                |                 |
    //                |             P1.4|-> Data Out (UCA0SIMO)
    //                |                 |
    //                |             P2.7|<- Data In (UCA0SOMI)
    //                |                 |
    //                |             P1.3|-> Serial Clock Out (UCA0CLK)

    while(!(P1IN&BIT3));                      // If clock sig from mstr stays low,
                                               // it is not yet in SPI mode

     PMAPPWD = 0x02D52;                        // Get write-access to port mapping regs
     P1MAP4 = PM_UCA0SIMO;                     // Map UCA0SIMO output to P1.4
     P2MAP7 = PM_UCA0SOMI;                     // Map UCA0SOMI output to P2.7
     P1MAP3 = PM_UCA0CLK;                      // Map UCA0CLK output to P1.3
     PMAPPWD = 0;                              // Lock port mapping registers

     P3DIR |= BIT0 + BIT1 + BIT2;              // ACLK, MCLK, SMCLK set out to pins
     P3SEL |= BIT0 + BIT1 + BIT2;              // P3.0,1,2 for debugging purposes

     UCA0CTL1 |= UCSWRST;                      // **Put state machine in reset**
     UCA0CTL0 |= UCSYNC+UCCKPL+UCMSB;          // 3-pin, 8-bit SPI slave,
                                               // Clock polarity high, MSB
     UCA0CTL1 &= ~UCSWRST;                     // **Initialize USCI state machine**
     UCA0IE |= UCRXIE;                         // Enable USCI_A0 RX interrupt

     __bis_SR_register(LPM4_bits + GIE);       // Enter LPM4, enable interrupts


     //Transmit some junk
     set_frequency(512000000); //Transmit at 512 MHz
     transmit_now();

	return 0;
}

// Echo character
#if defined(__TI_COMPILER_VERSION__) || defined(__IAR_SYSTEMS_ICC__)
#pragma vector=USCI_A0_VECTOR
__interrupt void USCI_A0_ISR(void)
#elif defined(__GNUC__)
void __attribute__ ((interrupt(USCI_A0_VECTOR))) USCI_A0_ISR (void)
#else
#error Compiler not supported!
#endif
{
  printf("Got an interrupt\r\n");
  switch(__even_in_range(UCA0IV,4))
  {
    case 0:break;                             // Vector 0 - no interrupt
    case 2:                                   // Vector 2 - RXIFG
      while (!(UCA0IFG&UCTXIFG));             // USCI_A0 TX buffer ready?
      UCA0TXBUF = UCA0RXBUF;
      printf("Sent a byte\r\n");
      break;
    case 4:break;                             // Vector 4 - TXIFG
    default: break;
  }
}

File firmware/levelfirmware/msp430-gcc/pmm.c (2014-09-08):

//****************************************************************************//
// Function Library for setting the PMM (Power Management Module)
//    File: hal_pmm.c
//
//    Texas Instruments
//
//    Version 1.2
//    11/24/09
//
//    V1.0  Initial Version
//    V1.1  Adjustment to UG
//    V1.2  Added return values
//****************************************************************************////====================================================================


/*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
* IN NO EVENT SHALL TI BE LIABLE FOR ANY SPECIAL, INCIDENTAL,
* CONSEQUENTIAL OR INDIRECT DAMAGES, HOWEVER CAUSED, ON ANY
* THEORY OF LIABILITY AND WHETHER OR NOT TI HAS BEEN ADVISED
* OF THE POSSIBILITY OF SUCH DAMAGES, ARISING IN ANY WAY OUT
* OF THIS AGREEMENT, THE PROGRAM, OR YOUR USE OF THE PROGRAM.
* EXCLUDED DAMAGES INCLUDE, BUT ARE NOT LIMITED TO, COST OF
* REMOVAL OR REINSTALLATION, COMPUTER TIME, LABOR COSTS, LOSS
* OF GOODWILL, LOSS OF PROFITS, LOSS OF SAVINGS, OR LOSS OF
* USE OR INTERRUPTION OF BUSINESS. IN NO EVENT WILL TI'S
* AGGREGATE LIABILITY UNDER THIS AGREEMENT OR ARISING OUT OF
* YOUR USE OF THE PROGRAM EXCEED FIVE HUNDRED DOLLARS
* (U.S.$500).
*
* Unless otherwise stated, the Program written and copyrighted
* by Texas Instruments is distributed as "freeware".  You may,
* only under TI's copyright in the Program, use and modify the
* Program without any charge or restriction.  You may
* distribute to third parties, provided that you transfer a
* copy of this license to the third party and the third party
* agrees to these terms by its first use of the Program. You
* must reproduce the copyright notice and any other legend of
* ownership on each copy or partial copy, of the Program.
*
* You acknowledge and agree that the Program contains
* copyrighted material, trade secrets and other TI proprietary
* information and is protected by copyright laws,
* international copyright treaties, and trade secret laws, as
* well as other intellectual property laws.  To protect TI's
* rights in the Program, you agree not to decompile, reverse
* engineer, disassemble or otherwise translate any object code
* versions of the Program to a human-readable form.  You agree
* that in no event will you alter, remove or destroy any
* copyright notice included in the Program.  TI reserves all
* rights not specifically granted under this license. Except
* as specifically provided herein, nothing in this agreement
* shall be construed as conferring by implication, estoppel,
* or otherwise, upon you, any license or other right under any
* TI patents, copyrights or trade secrets.
*
* You may not use the Program in non-TI devices.
* ********************************************************* */

#include "cc430f5137.h"
#include "pmm.h"

#define _HAL_PMM_DISABLE_SVML_
#define _HAL_PMM_DISABLE_SVSL_
#define _HAL_PMM_DISABLE_FULL_PERFORMANCE_


//****************************************************************************//
#ifdef _HAL_PMM_DISABLE_SVML_
#define _HAL_PMM_SVMLE SVMLE
#else
#define _HAL_PMM_SVMLE 0
#endif
#ifdef _HAL_PMM_DISABLE_SVSL_
#define _HAL_PMM_SVSLE SVSLE
#else
#define _HAL_PMM_SVSLE 0
#endif
#ifdef _HAL_PMM_DISABLE_FULL_PERFORMANCE_
#define _HAL_PMM_SVSFP SVSLFP
#else
#define _HAL_PMM_SVSFP 0
#endif
//****************************************************************************//
// Set VCore
//****************************************************************************//
unsigned int SetVCore (unsigned char level)
{
  unsigned int actlevel;
  unsigned int status = 0;
  level &= PMMCOREV_3;                       // Set Mask for Max. level
  actlevel = (PMMCTL0 & PMMCOREV_3);         // Get actual VCore

  while (((level != actlevel) && (status == 0)) || (level < actlevel))		// step by step increase or decrease
  {
    if (level > actlevel)
      status = SetVCoreUp(++actlevel);
    else
      status = SetVCoreDown(--actlevel);
  }
  return status;
}

//****************************************************************************//
// Set VCore Up
//****************************************************************************//
unsigned int SetVCoreUp (unsigned char level)
{
  unsigned int PMMRIE_backup, SVSMHCTL_backup;

  // Open PMM registers for write access
  PMMCTL0_H = 0xA5;

  // Disable dedicated Interrupts to prevent that needed flags will be cleared
  PMMRIE_backup = PMMRIE;
  PMMRIE &= ~(SVSMHDLYIE | SVSMLDLYIE | SVMLVLRIE | SVMHVLRIE | SVMHVLRPE);
  // Set SVM highside to new level and check if a VCore increase is possible
  SVSMHCTL_backup = SVSMHCTL;
  PMMIFG &= ~(SVMHIFG | SVSMHDLYIFG);
  SVSMHCTL = SVMHE | SVMHFP | (SVSMHRRL0 * level);
  // Wait until SVM highside is settled
  while ((PMMIFG & SVSMHDLYIFG) == 0);
  // Disable full-performance mode to save energy
  SVSMHCTL &= ~_HAL_PMM_SVSFP ;
  // Check if a VCore increase is possible
  if ((PMMIFG & SVMHIFG) == SVMHIFG){			//-> Vcc is to low for a Vcore increase
  	// recover the previous settings
  	PMMIFG &= ~SVSMHDLYIFG;
  	SVSMHCTL = SVSMHCTL_backup;
  	// Wait until SVM highside is settled
  	while ((PMMIFG & SVSMHDLYIFG) == 0);
  	// Clear all Flags
  	PMMIFG &= ~(SVMHVLRIFG | SVMHIFG | SVSMHDLYIFG | SVMLVLRIFG | SVMLIFG | SVSMLDLYIFG);
  	// backup PMM-Interrupt-Register
  	PMMRIE = PMMRIE_backup;

  	// Lock PMM registers for write access
  	PMMCTL0_H = 0x00;
  	return PMM_STATUS_ERROR;                       // return: voltage not set
  }
  // Set also SVS highside to new level			//-> Vcc is high enough for a Vcore increase
  SVSMHCTL |= SVSHE | (SVSHRVL0 * level);
  // Set SVM low side to new level
  SVSMLCTL = SVMLE | SVMLFP | (SVSMLRRL0 * level);
  // Wait until SVM low side is settled
  while ((PMMIFG & SVSMLDLYIFG) == 0);
  // Clear already set flags
  PMMIFG &= ~(SVMLVLRIFG | SVMLIFG);
  // Set VCore to new level
  PMMCTL0_L = PMMCOREV0 * level;
  // Wait until new level reached
  if (PMMIFG & SVMLIFG)
  while ((PMMIFG & SVMLVLRIFG) == 0);
  // Set also SVS/SVM low side to new level
  PMMIFG &= ~SVSMLDLYIFG;
  SVSMLCTL |= SVSLE | (SVSLRVL0 * level);
  // wait for lowside delay flags
  while ((PMMIFG & SVSMLDLYIFG) == 0);

// Disable SVS/SVM Low
// Disable full-performance mode to save energy
  SVSMLCTL &= ~(_HAL_PMM_DISABLE_SVSL_+_HAL_PMM_DISABLE_SVML_+_HAL_PMM_SVSFP );

  // Clear all Flags
  PMMIFG &= ~(SVMHVLRIFG | SVMHIFG | SVSMHDLYIFG | SVMLVLRIFG | SVMLIFG | SVSMLDLYIFG);
  // backup PMM-Interrupt-Register
  PMMRIE = PMMRIE_backup;

  // Lock PMM registers for write access
  PMMCTL0_H = 0x00;
  return PMM_STATUS_OK;                               // return: OK
}
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

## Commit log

2014-09-08 Started working on SPI comm
2014-09-19 Mechanical mockup
    [enclosure bottom.SLDPRT, enclosure top.SLDPRT]
2014-09-20 Started porting schematic to KiCAD
    [CC430_tap.sch, LNA_and_antenna.sch, LO.sch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]
2014-09-26 Added taps to schematic
    [CC430_tap.sch, LNA_and_antenna.sch, LO.sch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]
2014-09-27 Finished port from Altium to KiCAD
    [CC430_tap.sch, LNA_and_antenna.sch, LO.sch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]
